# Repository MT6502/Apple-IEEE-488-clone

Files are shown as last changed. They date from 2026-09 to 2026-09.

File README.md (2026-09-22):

# Apple-IEEE-488-clone
the schematic is based on the original documented
in the IEEE-488 interface manual from Apple with some smaller changes, mainly for easier routing the board.
The manual can be found at several places in the internet. 
Actually the following links will work:
https://www.applefritter.com/files/2021/08/15/Apple%20%5D%5B%20___%20IEEE-488%20Interface%20Users%20Guide.pdf
the rom can be found here, no other source found yet:
https://www.applefritter.com/files/2021/09/19/Apple%20IEEE%20488%20ROM%20Dump.BIN_.zip
corosponnding chat @Applefritter:
https://www.applefritter.com/content/apple-ieee-488-interface-card

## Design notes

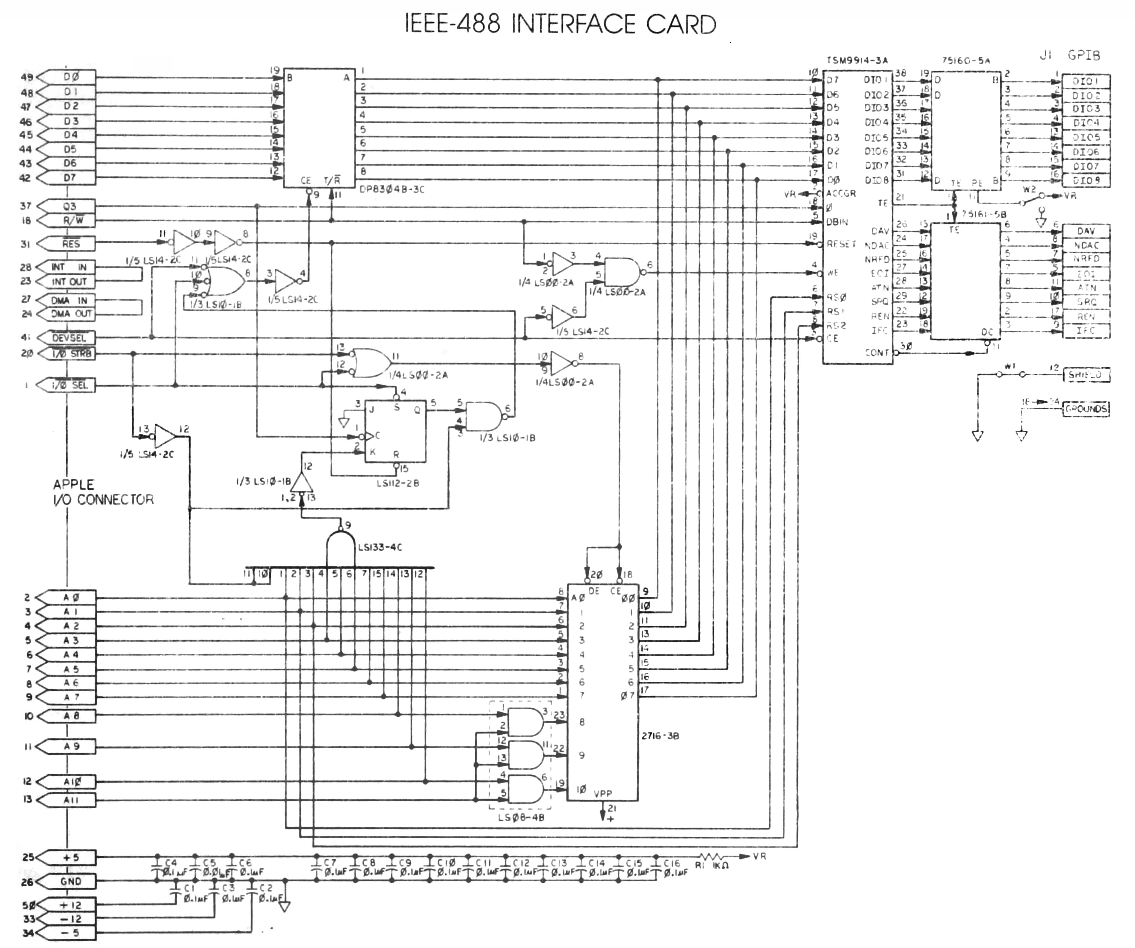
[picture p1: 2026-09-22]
Apple_II-IEEE-488/Documentation/Apple ][ IEEE-488 Interface Schematic.jpg

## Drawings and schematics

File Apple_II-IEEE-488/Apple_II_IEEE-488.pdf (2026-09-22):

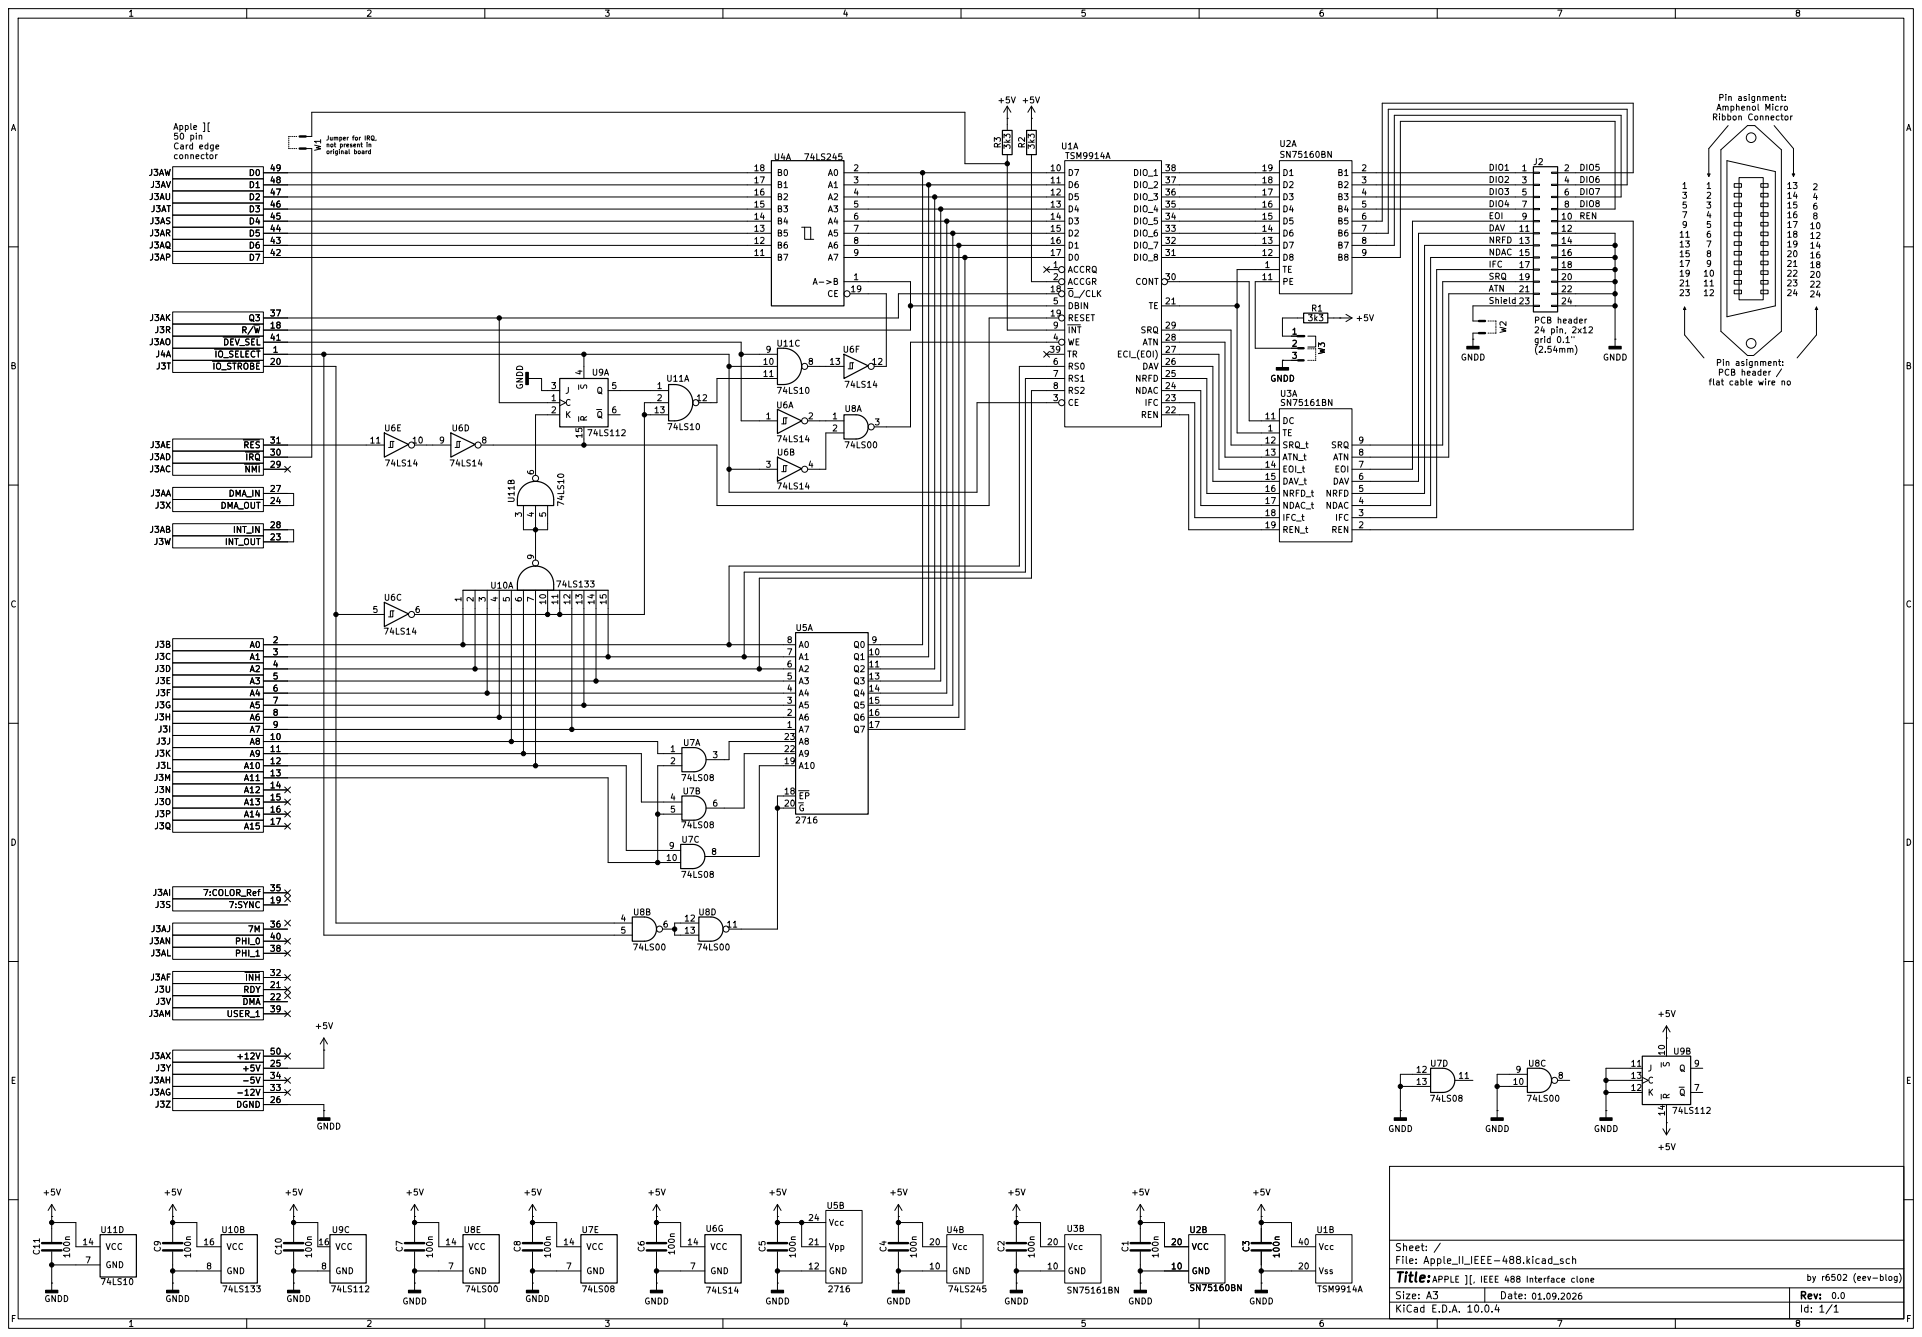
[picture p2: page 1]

Amphenol Micro Ribbon Connector

Apple ][ 50 pin Card edge connector

Jumper for IRQ, not present in

ACCRQ 1 | IFC 17 | 18

SRQ 19 | 20
ATN 21 | 22

flat cable wire no PCB header 24 pin, 2x12

APPLE ][, IEEE 488 Interface clone 01.09.2026

Size: A3 | Rev:
KiCad E.D.A. 10.0.4 | Id: 1/1 | F Date:

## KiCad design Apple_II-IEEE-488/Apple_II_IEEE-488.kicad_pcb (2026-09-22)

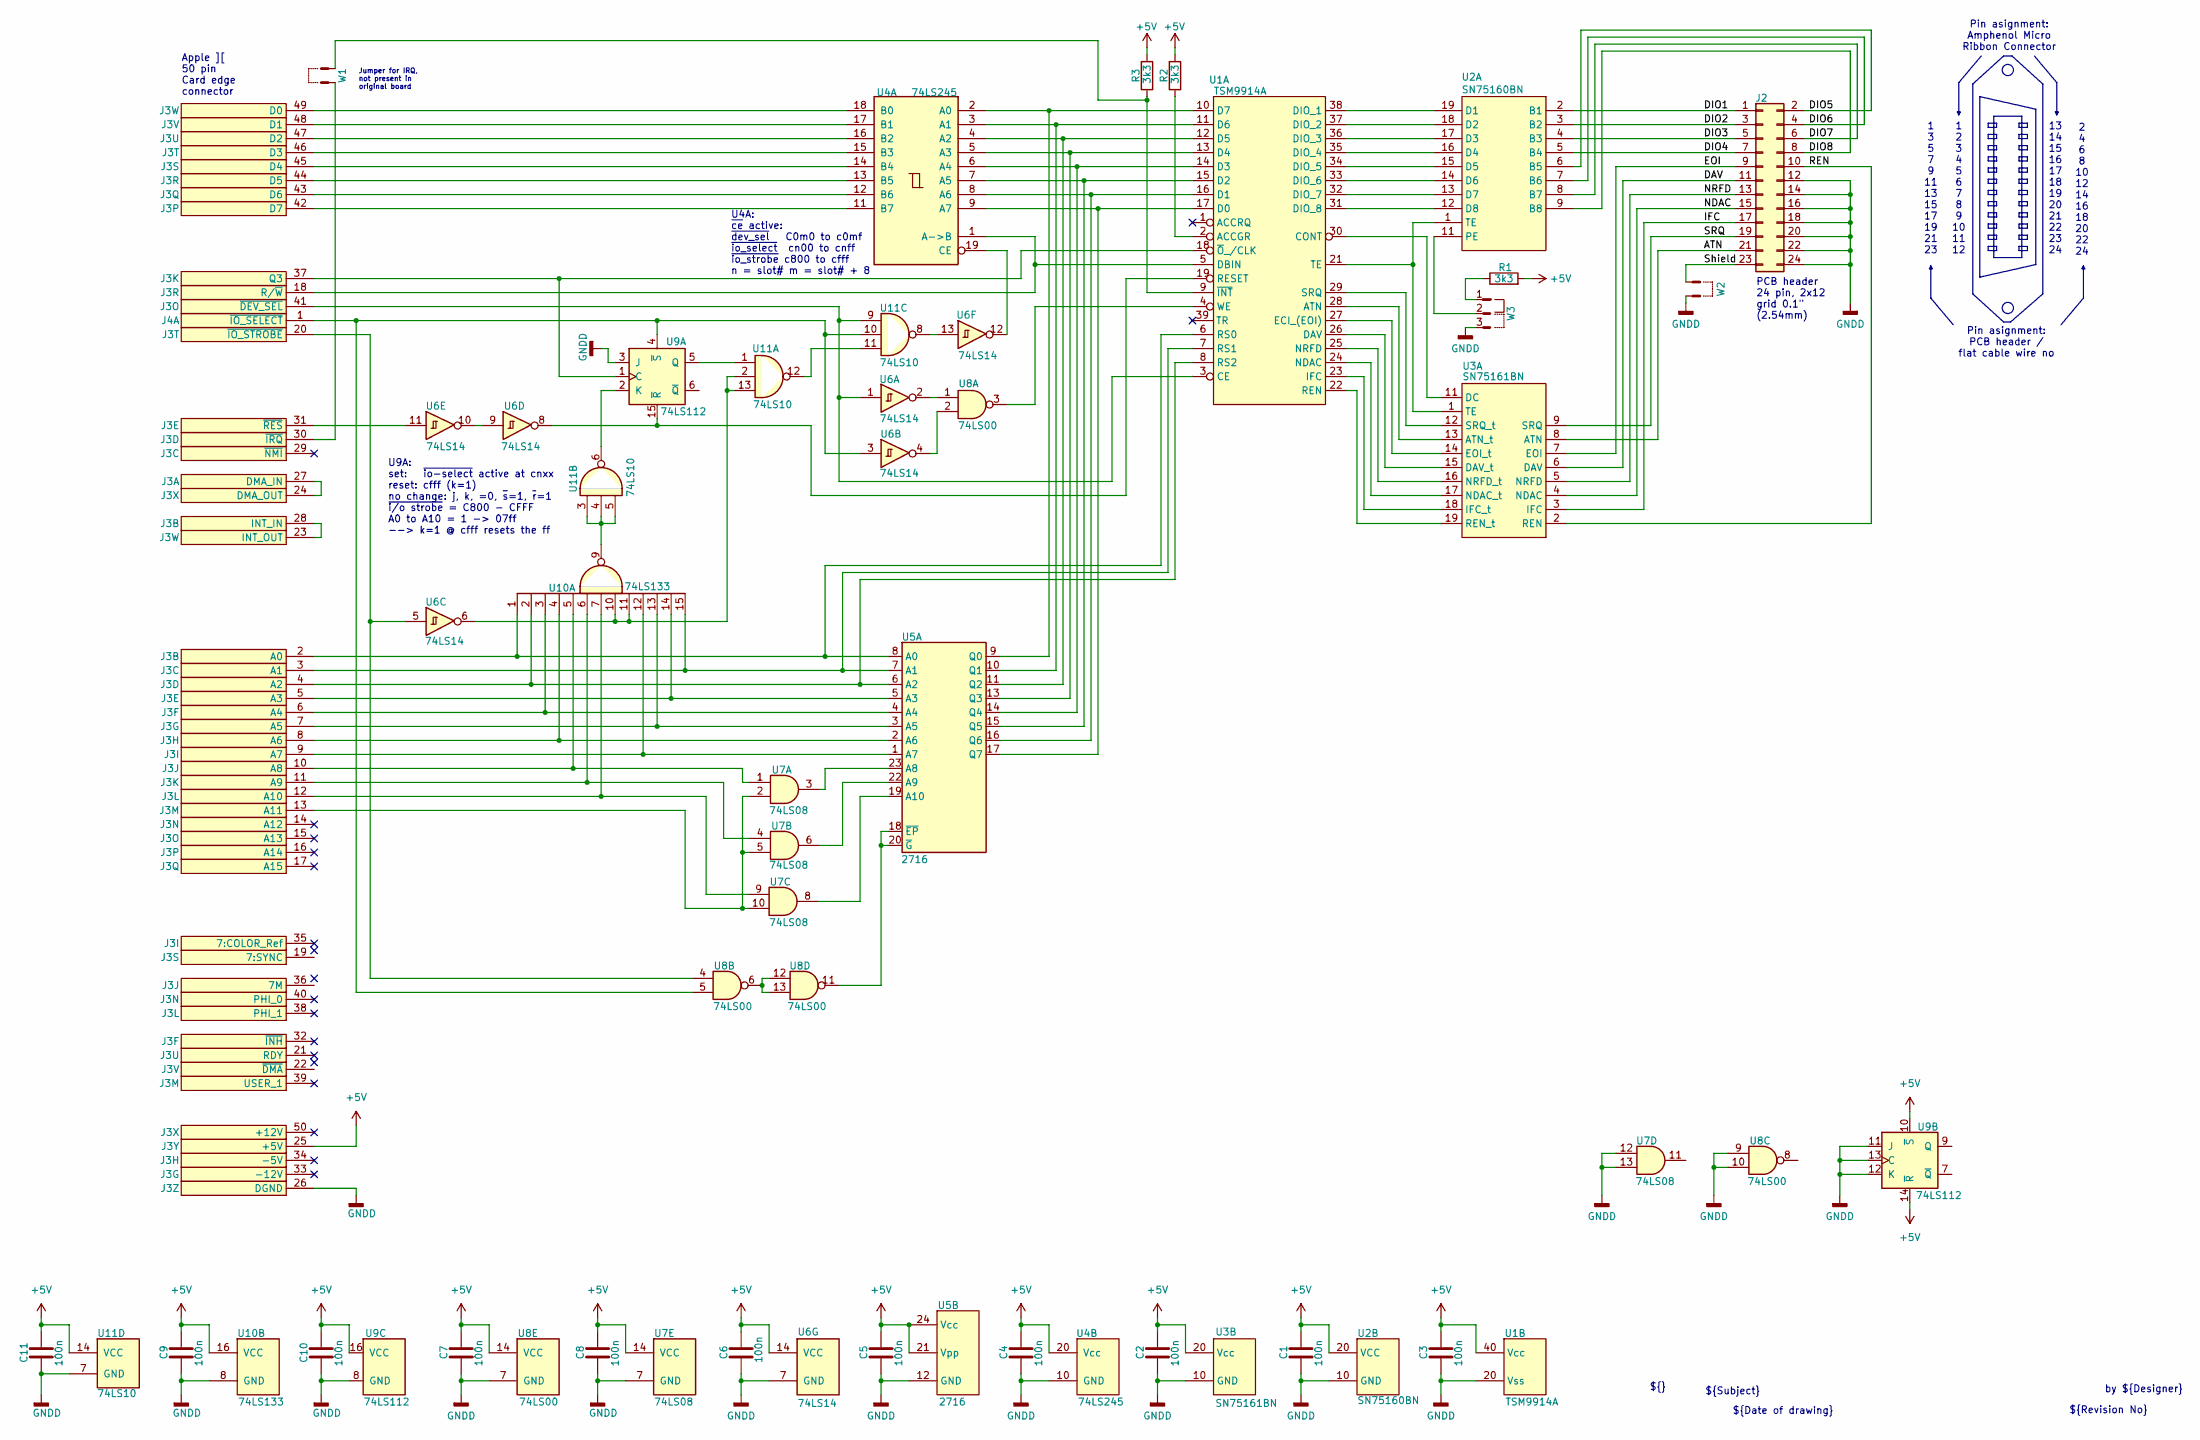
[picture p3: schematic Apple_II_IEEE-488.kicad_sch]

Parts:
C1, C2, C3, C4, C5, C6, C7, C8, C9, C10, C11: 100n; C_disk_2.54mm
J2: Conn_02x12_Odd_Even; IDC-Header_2x12_P2.54mm_Vertical
J3: Apple_II_card_edge
J4: (no value)
R1, R2, R3: 3k3; R_Axial_L3.6mm_D1.6mm_P2.54mm_Vertical
U1: TSM9914A; DIP-40_W15.24mm
U2: SN75160BN; DIP-20_W7.62mm
U3: SN75161BN; DIP-20_W7.62mm
U4: 74LS245; DIP-20_W7.62mm
U5: 2716; DIP-24_17.53mmx33.02mm_W15.24mm_sb
U6: 74LS14; DIP-14_W7.62mm
U7: 74LS08; DIP-14_W7.62mm
U8: 74LS00; DIP-14_W7.62mm
U9: 74LS112; DIP-16_W7.62mm
U10: 74LS133; DIP-16_W7.62mm
U11: 74LS10; DIP-14_W7.62mm
W1, W2: JP_2pin
W3: Jumper2pos

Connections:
+5V: C1.1, C2.1, C3.1, C4.1, C5.1, C6.1, C7.1, C8.1, C9.1, C10.1, C11.1, J3.25 (+5V), R1.2, R2.2, R3.2, U1.40 (Vcc), U2.20 (VCC), U3.20 (Vcc), U4.20 (Vcc), U5.21 (Vpp), U5.24 (Vcc), U6.14 (VCC), U7.14 (VCC), U8.14 (VCC), U9.10 (~S), U9.14 (~R), U9.16 (VCC), U10.16 (VCC), U11.14 (VCC)
/ATN: J2.21, U3.8 (ATN)
/DAV: J2.11, U3.6 (DAV)
/DIO1: J2.1, U2.2 (B1)
/DIO2: J2.3, U2.3 (B2)
/DIO3: J2.5, U2.4 (B3)
/DIO4: J2.7, U2.5 (B4)
/DIO5: J2.2, U2.6 (B5)
/DIO6: J2.4, U2.7 (B6)
/DIO7: J2.6, U2.8 (B7)
/DIO8: J2.8, U2.9 (B8)
/EOI: J2.9, U3.7 (EOI)
/IFC: J2.17, U3.3 (IFC)
/NDAC: J2.15, U3.4 (NDAC)
/NRFD: J2.13, U3.5 (NRFD)
/REN: J2.10, U3.2 (REN)
/SRQ: J2.19, U3.9 (SRQ)
/Shield: J2.23, W2.2
GNDD: C1.2, C2.2, C3.2, C4.2, C5.2, C6.2, C7.2, C8.2, C9.2, C10.2, C11.2, J2.12, J2.14, J2.16, J2.18, J2.20, J2.22, J2.24, J3.26 (DGND), U1.20 (Vss), U2.10 (GND), U3.10 (GND), U4.10 (GND), U5.12 (GND), U6.7 (GND), U7.7 (GND), U7.12, U7.13, U8.7 (GND), U8.9, U8.10, U9.3 (J), U9.8 (GND), U9.11 (J), U9.12 (K), U9.13 (C), U10.8 (GND), U11.7 (GND), W2.1, W3.3
unnamed: J3.24 (DMA_OUT), J3.27 (DMA_IN)
unnamed: J3.23 (INT_OUT), J3.28 (INT_IN)
unnamed: J3.30 (~IRQ), W1.1
unnamed: J3.31 (~RES), U6.11
unnamed: J3.37 (Q3), U1.18 (~O_/CLK), U9.1 (C)
unnamed: J3.41 (~DEV_SEL), U1.3 (CE), U6.1, U11.9
unnamed: J3.42 (D7), U4.11 (B7)
unnamed: J3.43 (D6), U4.12 (B6)
unnamed: J3.44 (D5), U4.13 (B5)
unnamed: J3.45 (D4), U4.14 (B4)
unnamed: J3.46 (D3), U4.15 (B3)
unnamed: J3.47 (D2), U4.16 (B2)
unnamed: J3.48 (D1), U4.17 (B1)
unnamed: J3.49 (D0), U4.18 (B0)
unnamed: J3.2 (A0), U1.6 (RS0), U5.8 (A0), U10.1
unnamed: J3.3 (A1), U1.7 (RS1), U5.7 (A1), U10.15
unnamed: J3.4 (A2), U1.8 (RS2), U5.6 (A2), U10.2
unnamed: J3.5 (A3), U5.5 (A3), U10.14
unnamed: J3.6 (A4), U5.4 (A4), U10.3
unnamed: J3.7 (A5), U5.3 (A5), U10.13
unnamed: J3.8 (A6), U5.2 (A6), U10.4
unnamed: J3.9 (A7), U5.1 (A7), U10.12
unnamed: J3.10 (A8), U7.1, U10.5
unnamed: J3.11 (A9), U7.4, U10.6
unnamed: J3.12 (A10), U7.9, U10.7
unnamed: J3.13 (A11), U7.2, U7.5, U7.10
unnamed: J3.18 (R/~W), U1.5 (DBIN), U4.1 (A->B)
unnamed: J3.20 (~IO_STROBE), U6.5, U8.4
unnamed: J4.1 (~IO_SELECT), U6.3, U8.5, U9.4 (~S), U11.10
unnamed: R1.1, W3.1
unnamed: R2.1, U1.2 (ACCGR)
unnamed: U1.28 (ATN), U3.13 (ATN_t)
unnamed: U1.30 (CONT), U3.11 (DC)
unnamed: U1.17 (D0), U4.9 (A7), U5.17 (Q7)
unnamed: U1.16 (D1), U4.8 (A6), U5.16 (Q6)
unnamed: U1.15 (D2), U4.7 (A5), U5.15 (Q5)
unnamed: U1.14 (D3), U4.6 (A4), U5.14 (Q4)
unnamed: U1.13 (D4), U4.5 (A3), U5.13 (Q3)
unnamed: U1.12 (D5), U4.4 (A2), U5.11 (Q2)
unnamed: U1.11 (D6), U4.3 (A1), U5.10 (Q1)
unnamed: U1.10 (D7), U4.2 (A0), U5.9 (Q0)
unnamed: U1.26 (DAV), U3.15 (DAV_t)
unnamed: U1.38 (DIO_1), U2.19 (D1)
unnamed: U1.37 (DIO_2), U2.18 (D2)
unnamed: U1.36 (DIO_3), U2.17 (D3)
unnamed: U1.35 (DIO_4), U2.16 (D4)
unnamed: U1.34 (DIO_5), U2.15 (D5)
unnamed: U1.33 (DIO_6), U2.14 (D6)
unnamed: U1.32 (DIO_7), U2.13 (D7)
unnamed: U1.31 (DIO_8), U2.12 (D8)
unnamed: U1.27 (ECI_(EOI)), U3.14 (EOI_t)
unnamed: U1.23 (IFC), U3.18 (IFC_t)
unnamed: U1.24 (NDAC), U3.17 (NDAC_t)
unnamed: U1.25 (NRFD), U3.16 (NRFD_t)
unnamed: U1.22 (REN), U3.19 (REN_t)
unnamed: U1.19 (RESET), U6.8, U9.15 (~R)
unnamed: U1.29 (SRQ), U3.12 (SRQ_t)
unnamed: U1.21 (TE), U2.1 (TE), U3.1 (TE)
unnamed: U1.4 (WE), U8.3
unnamed: R3.1, U1.9 (~INT), W1.2
unnamed: U2.11 (PE), W3.2
unnamed: U4.19 (CE), U6.12
unnamed: U5.23 (A8), U7.3
unnamed: U5.22 (A9), U7.6
unnamed: U5.19 (A10), U7.8
unnamed: U5.18 (~EP), U5.20 (~G), U8.11
unnamed: U6.2, U8.1
unnamed: U6.4, U8.2
unnamed: U6.9, U6.10
unnamed: U8.6, U8.12, U8.13
unnamed: U9.2 (K), U11.6
unnamed: U9.5 (Q), U11.1
unnamed: U10.9, U11.3, U11.4, U11.5
unnamed: U6.6, U10.10, U10.11, U11.2, U11.13
unnamed: U6.13, U11.8
unnamed: U11.11, U11.12

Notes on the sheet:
2 4 6 8 10 12 14 16 18 20 22 24
1 2 3 4 5 6 7 8 9 10 11 12
${Date of drawing}
U4A: ~{ce} active: ~{dev_sel} C0m0 to c0mf ~{io_select} cn00 to cnff ~{io_strobe} c800 to cfff n = slot# m = slot# + 8
13 14 15 16 17 18 19 20 21 22 23 24
PCB header 24 pin, 2x12 grid 0.1" (2.54mm)
Apple ][ 50 pin Card edge connector
by ${Designer}
${Subject}
1 3 5 7 9 11 13 15 17 19 21 23
${Revision No}
U9A: set: ~{io-select} active at cnxx reset: cfff (k=1) no change: j, k, =0, ~{s}=1, ~{r}=1 ~{i/o strobe} = C800 - CFFF A0 to A10 = 1 -> 07ff --> k=1 @ cfff resets the ff
${}
Pin asignment: Amphenol Micro Ribbon Connector
Pin asignment: PCB header / flat cable wire no
Jumper for IRQ, not present in original board

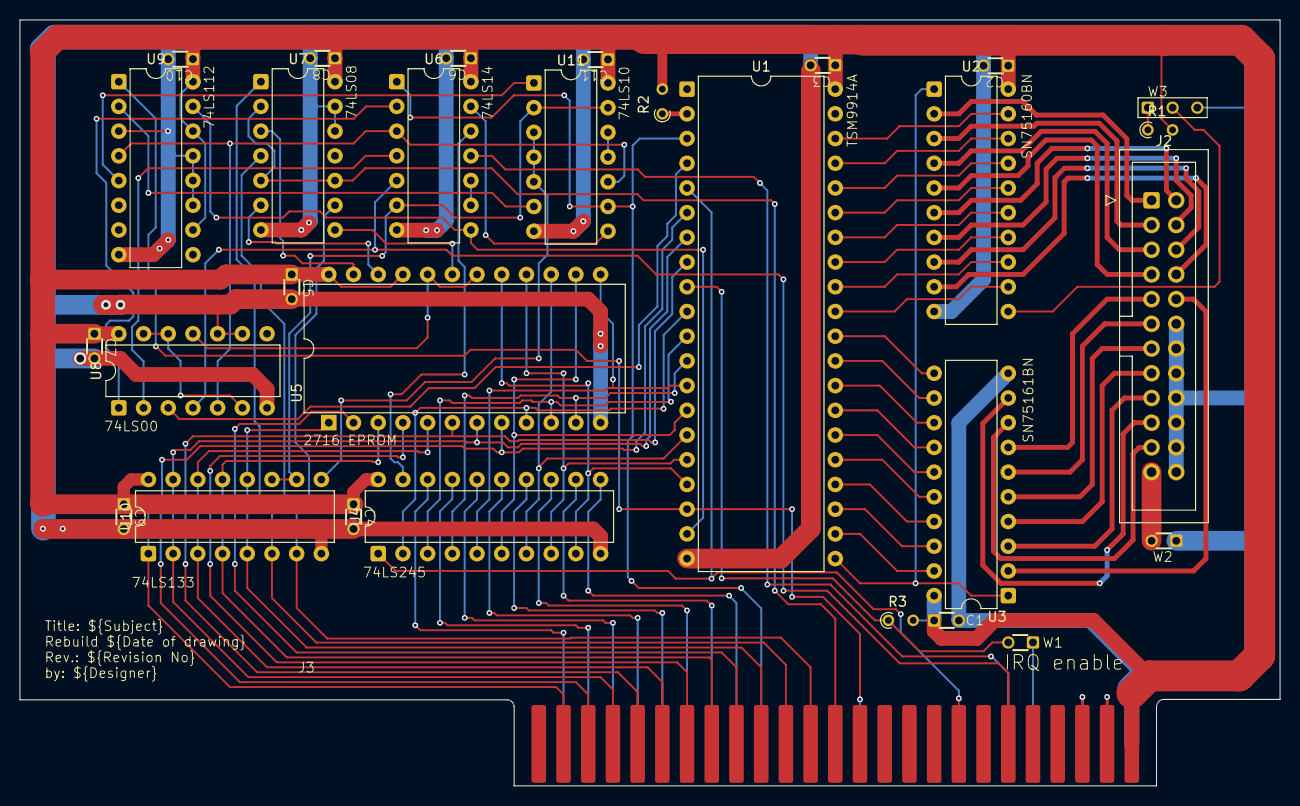
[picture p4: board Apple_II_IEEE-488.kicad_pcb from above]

Board: 2 copper layers, 129.5 x 78.7 mm, 30 parts (0 on the bottom side), 95 nets.
